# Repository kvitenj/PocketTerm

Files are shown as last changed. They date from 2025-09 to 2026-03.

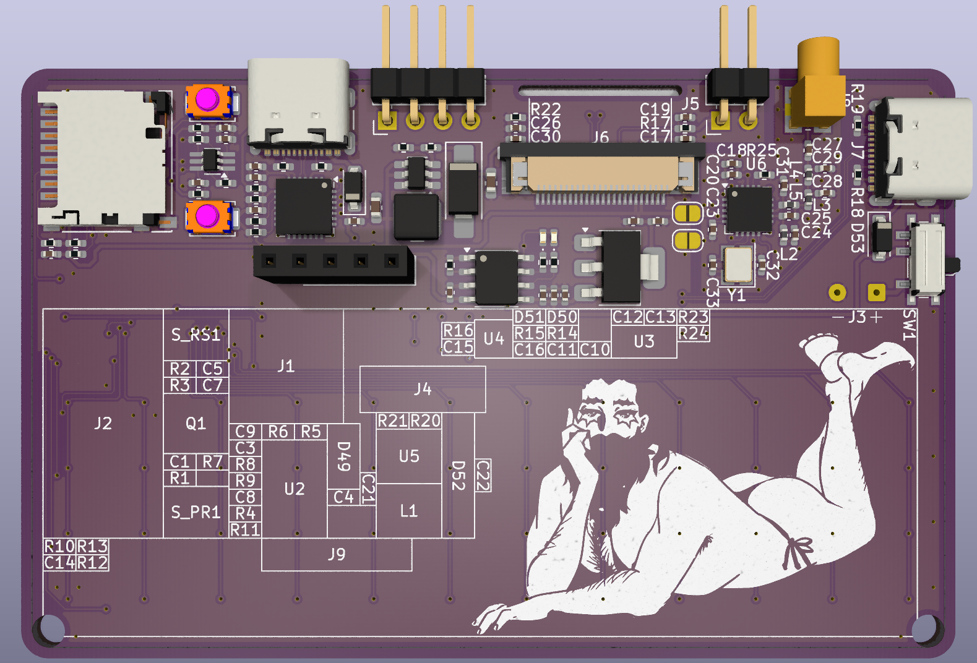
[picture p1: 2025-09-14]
images/board_back.png

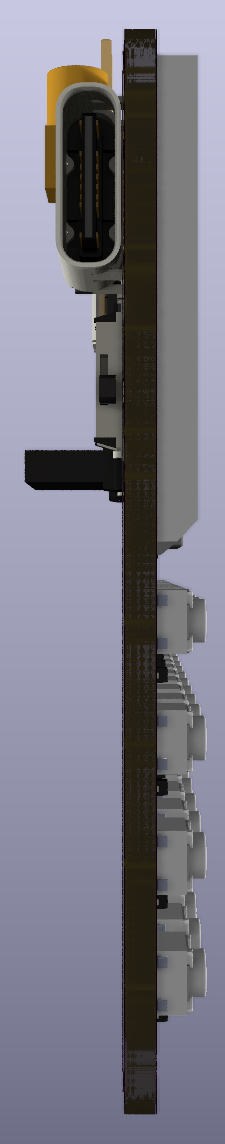
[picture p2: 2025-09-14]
images/board_side.png

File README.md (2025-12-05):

# PocketTerminal

A credit card-sized computer for wireless and wired communication debugging

real_frontreal_backreal_case

---

## 🔖 Overview

The project is inspired by the [M5Stack Cardputer](https://docs.m5stack.com/en/core/Cardputer%20V1.1).

The key features:

- Credit card size to easily fit in any pocket
- QWERTY tactile keyboard for easy and fast command and data input
- "Large" 2.2-inch OLED monochrome LCD with 128x32 resolution. It is monochrome and has less resolution than M5Stack, but it is larger and fits nicely for text terminal data
- ESP32 module as a central processing unit capable of Bluetooth and WiFi communication
- SD card slot for Data storage
- Large and slim battery for long-term operation
- UART, SPI, I2C(TBD) I/O for wired communication debugging
- CC1101 and LoRa(TBD) transceivers for wireless communication debugging

---

## 📁 Repository Contents

| File | Description |
|---|---|
| `PocketTerminalHW` | Folder containing the KiCAD project, PCB and Schematic |
| `images` | Folder containing the concept renders | 
| `LICENSE` | This repository license file |
| `README.md` | This file |

---

## 📬 Contributing

You may submit pull requests or fork the repo. But since it is a hobby project, I may respond with significant delays

---

## 🌸 License

Licensed under the [Flower License](./LICENSE) 🌸

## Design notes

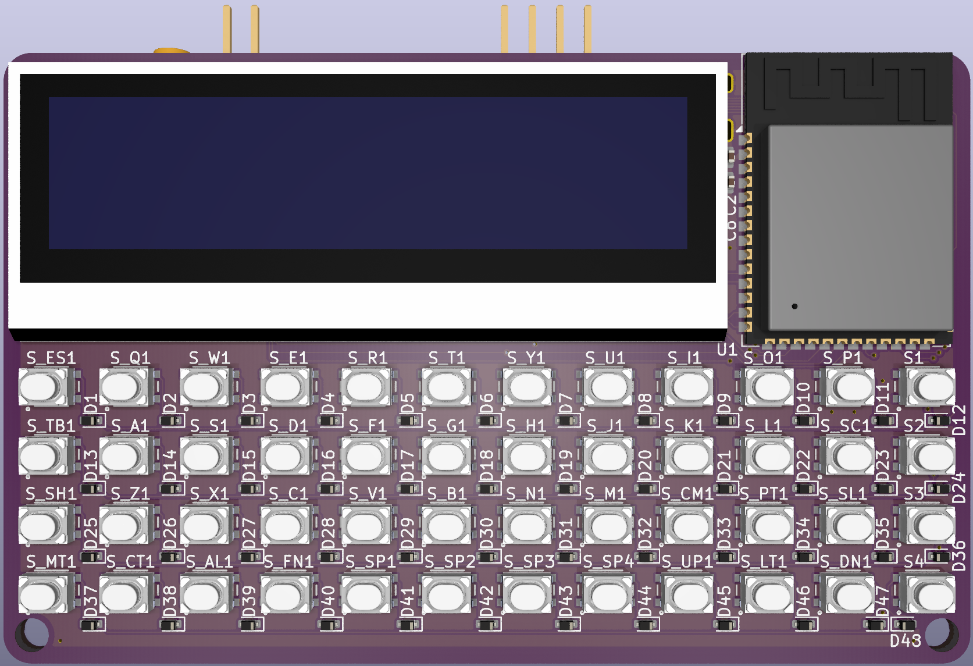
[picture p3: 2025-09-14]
images/board_front.png

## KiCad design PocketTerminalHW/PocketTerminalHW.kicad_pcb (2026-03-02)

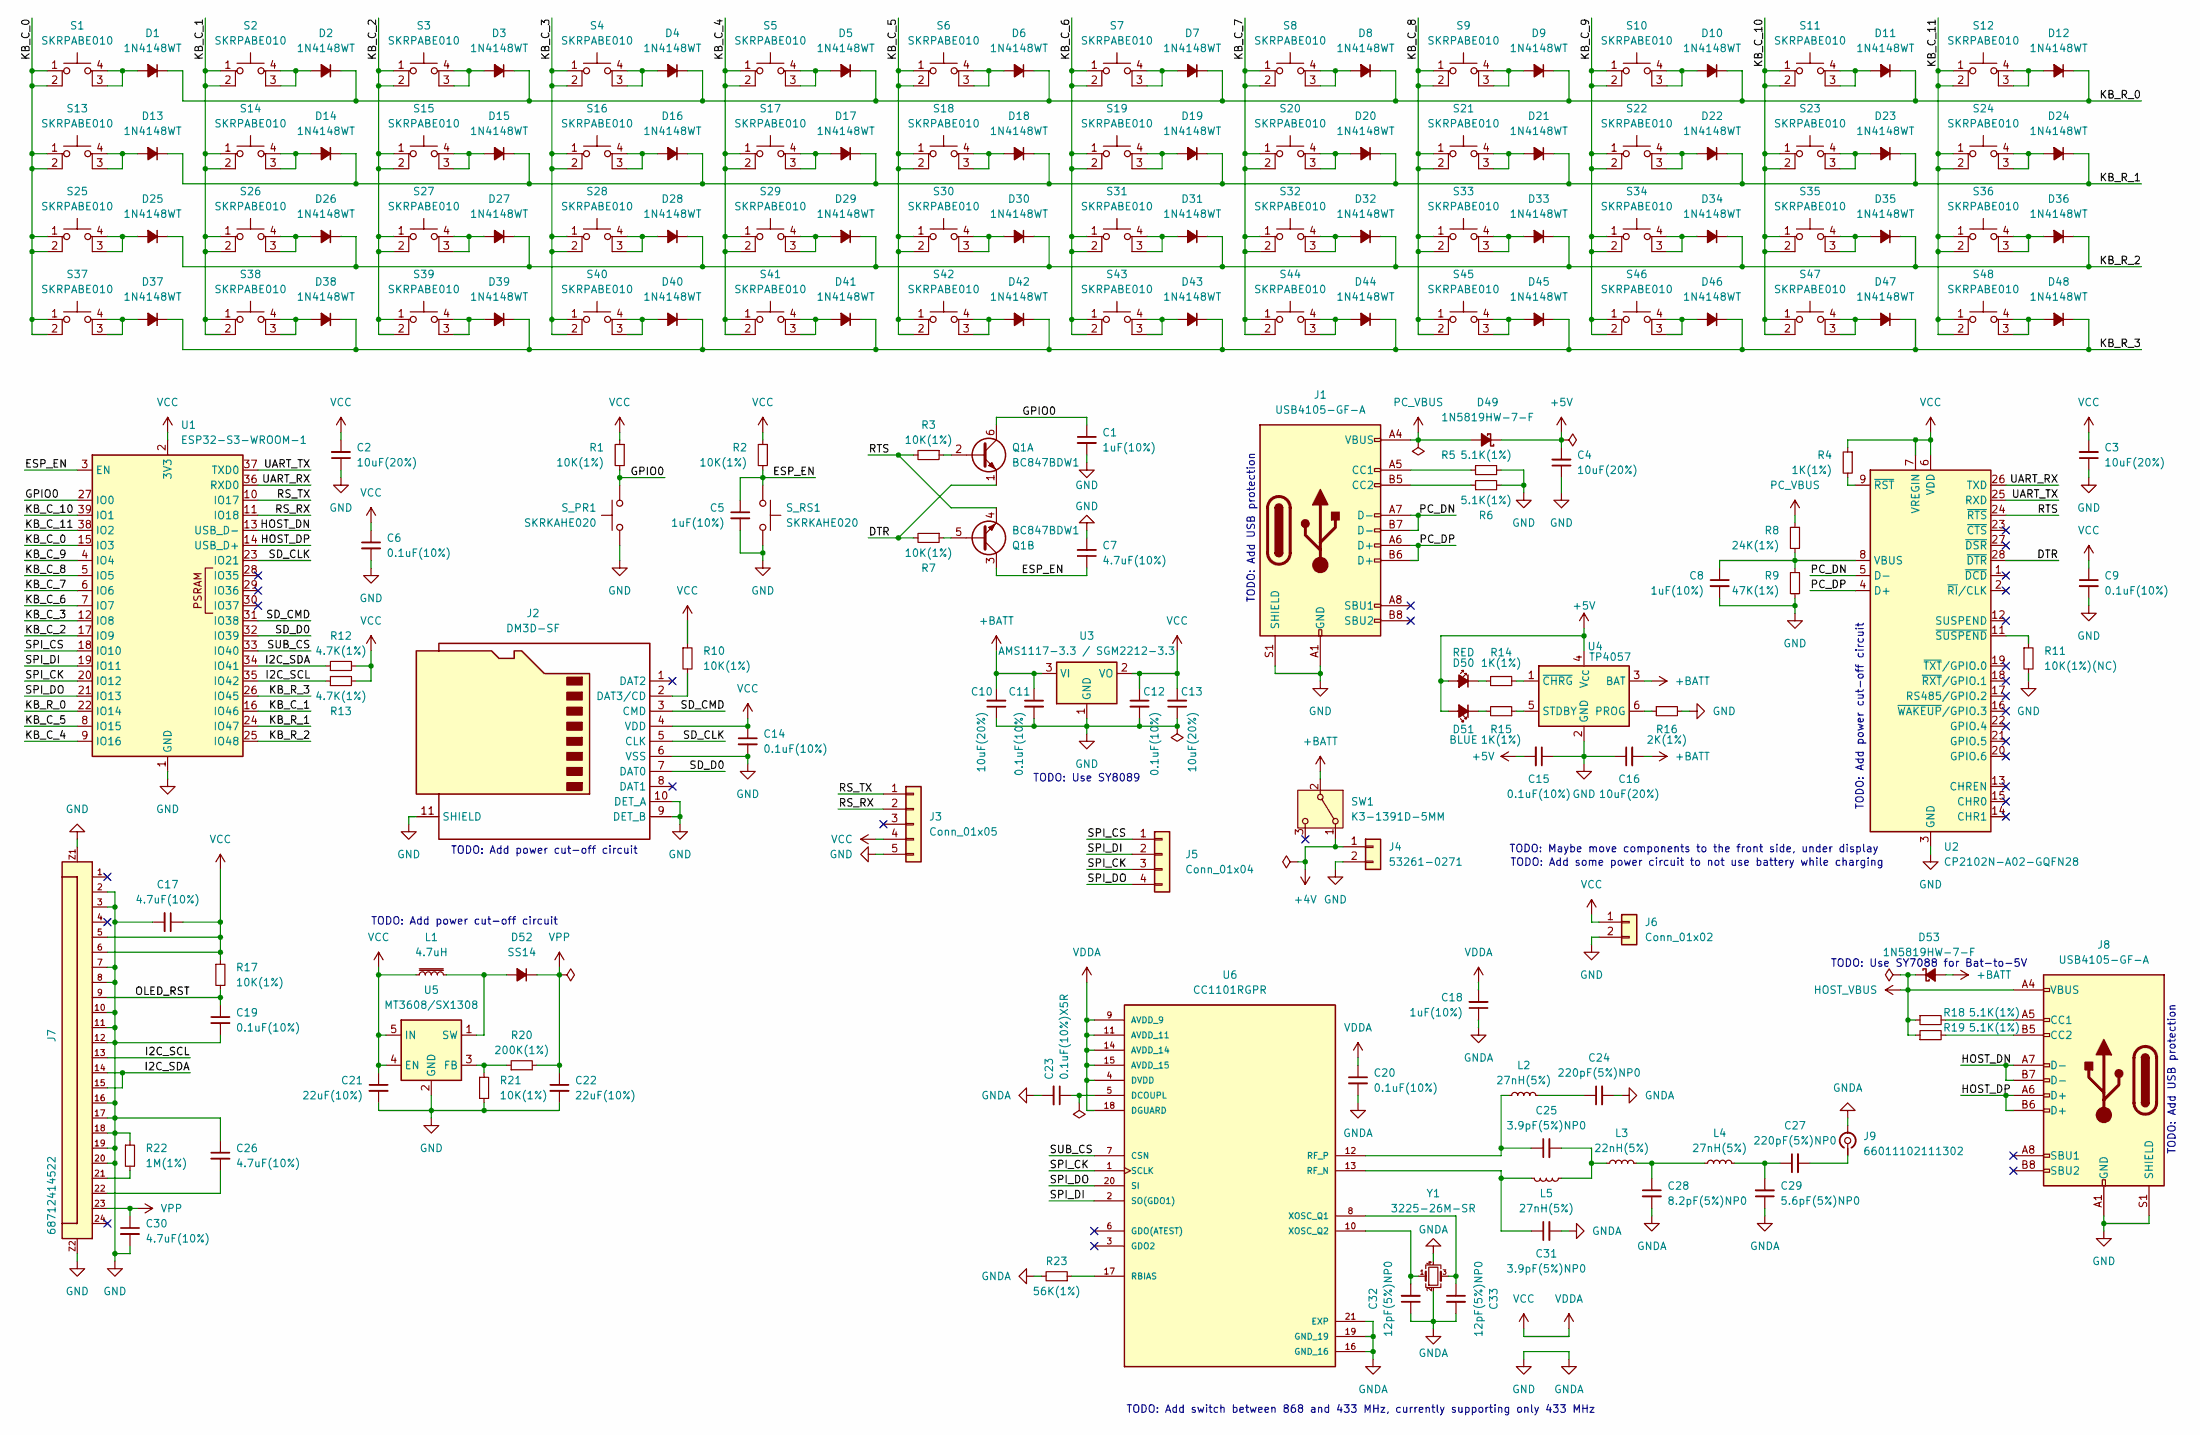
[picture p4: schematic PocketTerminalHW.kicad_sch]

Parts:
C1, C5, C8, C18: 1uF(10%); C_0402_1005Metric_Pad0.74x0.62mm_HandSolder
C2, C3, C4, C10, C13, C16: 10uF(20%); C_0402_1005Metric_Pad0.74x0.62mm_HandSolder
C6, C9, C11, C12, C14, C15, C19, C20: 0.1uF(10%); C_0402_1005Metric_Pad0.74x0.62mm_HandSolder
C7, C17, C26, C30: 4.7uF(10%); C_0402_1005Metric_Pad0.74x0.62mm_HandSolder
C21, C22: 22uF(10%); C_0603_1608Metric_Pad1.08x0.95mm_HandSolder
C23: 0.1uF(10%)X5R; C_0402_1005Metric_Pad0.74x0.62mm_HandSolder
C24, C27: 220pF(5%)NP0; C_0402_1005Metric_Pad0.74x0.62mm_HandSolder
C25, C31: 3.9pF(5%)NP0; C_0402_1005Metric_Pad0.74x0.62mm_HandSolder
C28: 8.2pF(5%)NP0; C_0402_1005Metric_Pad0.74x0.62mm_HandSolder
C29: 5.6pF(5%)NP0; C_0402_1005Metric_Pad0.74x0.62mm_HandSolder
C32, C33: 12pF(5%)NP0; C_0402_1005Metric_Pad0.74x0.62mm_HandSolder
D1, D2, D3, D4, D5, D6, D7, D8, D9, D10, D11, D12, D13, D14, D15, D16, D17, D18, D19, D20, D21, D22, D23, D24, D25, D26, D27, D28, D29, D30, D31, D32, D33, D34, D35, D36, D37, D38, D39, D40, D41, D42, D43, D44, D45, D46, D47, D48: 1N4148WT; D_SOD-523
D49, D53: 1N5819HW-7-F; D_SOD-123
D50: RED; LED_0402_1005Metric
D51: BLUE; LED_0402_1005Metric
D52: SS14; D_SMA
J1, J8: USB4105-GF-A; USB_C_Receptacle_GCT_USB4105-xx-A_16P_TopMnt_Horizontal
J2: DM3D-SF; microSD_HC_Hirose_DM3D-SF
J3: Conn_01x05; PinSocket_1x05_P2.54mm_Vertical
J4: 53261-0271; SolderWire-0.1sqmm_1x02_P3.6mm_D0.4mm_OD1mm
J5: Conn_01x04; PinHeader_1x04_P2.54mm_Horizontal
J6: Conn_01x02; PinHeader_1x02_P2.54mm_Horizontal
J7: 68712414522
J9: 66011102111302; WR-MMCX_Wuerth_66011102111302_Horizontal
L1: 4.7uH; L_Coilcraft_LPS4018
L2, L4, L5: 27nH(5%); L_0402_1005Metric_Pad0.77x0.64mm_HandSolder
L3: 22nH(5%); L_0402_1005Metric_Pad0.77x0.64mm_HandSolder
Q1: BC847BDW1; SOT-363_SC-70-6_Handsoldering
R1, R2, R3, R7, R10, R17, R21: 10K(1%); R_0402_1005Metric_Pad0.72x0.64mm_HandSolder
R4, R14, R15: 1K(1%); R_0402_1005Metric_Pad0.72x0.64mm_HandSolder
R5, R6, R18, R19: 5.1K(1%); R_0402_1005Metric_Pad0.72x0.64mm_HandSolder
R8: 24K(1%); R_0402_1005Metric_Pad0.72x0.64mm_HandSolder
R9: 47K(1%); R_0402_1005Metric_Pad0.72x0.64mm_HandSolder
R11: 10K(1%)(NC); R_0402_1005Metric_Pad0.72x0.64mm_HandSolder
R12, R13: 4.7K(1%); R_0402_1005Metric_Pad0.72x0.64mm_HandSolder
R16: 2K(1%); R_0402_1005Metric_Pad0.72x0.64mm_HandSolder
R20: 200K(1%); R_0402_1005Metric_Pad0.72x0.64mm_HandSolder
R22: 1M(1%); R_0402_1005Metric_Pad0.72x0.64mm_HandSolder
R23: 56K(1%); R_0402_1005Metric_Pad0.72x0.64mm_HandSolder
S1, S2, S3, S4, S5, S6, S7, S8, S9, S10, S11, S12, S13, S14, S15, S16, S17, S18, S19, S20, S21, S22, S23, S24, S25, S26, S27, S28, S29, S30, S31, S32, S33, S34, S35, S36, S37, S38, S39, S40, S41, S42, S43, S44, S45, S46, S47, S48: SKRPABE010; SW4_SKRPABE010_ALPS
SW1: K3-1391D-5MM; SW_SPDT_PCM12
S_PR1: SKRKAHE020; SW_Push_SPST_NO_Alps_SKRK
S_RS1: SKRKAHE020; SW_Push_SPST_NO_Alps_SKRK
U1: ESP32-S3-WROOM-1
U2: CP2102N-A02-GQFN28; QFN-28-1EP_5x5mm_P0.5mm_EP3.35x3.35mm
U3: AMS1117-3.3 / SGM2212-3.3; SOT-223-3_TabPin2
U4: TP4057; TSOT-23-6
U5: MT3608/SX1308; SOT-23-6_Handsoldering
U6: CC1101RGPR; QFN-20-1EP_4x4mm_P0.5mm_EP2.5x2.5mm; PARTREV 6-May-2020
Y1: 3225-26M-SR; Crystal_SMD_3225-4Pin_3.2x2.5mm

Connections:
+4V: J4.1, SW1.1 (A)
+5V: C4.2, C15.2, D49.1 (K), D50.2 (A), D51.2 (A), U4.4 (V_{CC})
+BATT: C10.2, C11.1, C16.2, D53.2 (A), SW1.2 (B), U3.3 (VI), U4.3 (BAT)
/DTR: Q1.1 (E1), R7.2, U2.28 (~DTR)
/ESP_EN: C5.1, C7.1, Q1.3 (C2), R2.2, S_RS1.1, U1.3 (EN)
/GPIO0: C1.1, Q1.6 (C1), R1.2, S_PR1.1, U1.27 (IO0)
/HOST_DN: J8.A7 (D-), J8.B7 (D-), U1.13 (USB_D-)
/HOST_DP: J8.A6 (D+), J8.B6 (D+), U1.14 (USB_D+)
/I2C_SCL: J7.13, R13.1, U1.35 (IO42)
/I2C_SDA: J7.14, J7.15, R12.1, U1.34 (IO41)
/KB_C_0: S1.1, S1.2, S13.1, S13.2, S25.1, S25.2, S37.1, S37.2, U1.15 (IO3)
/KB_C_1: S2.1, S2.2, S14.1, S14.2, S26.1, S26.2, S38.1, S38.2, U1.16 (IO46)
/KB_C_2: S3.1, S3.2, S15.1, S15.2, S27.1, S27.2, S39.1, S39.2, U1.17 (IO9)
/KB_C_3: S4.1, S4.2, S16.1, S16.2, S28.1, S28.2, S40.1, S40.2, U1.12 (IO8)
/KB_C_4: S5.1, S5.2, S17.1, S17.2, S29.1, S29.2, S41.1, S41.2, U1.9 (IO16)
/KB_C_5: S6.1, S6.2, S18.1, S18.2, S30.1, S30.2, S42.1, S42.2, U1.8 (IO15)
/KB_C_6: S7.1, S7.2, S19.1, S19.2, S31.1, S31.2, S43.1, S43.2, U1.7 (IO7)
/KB_C_7: S8.1, S8.2, S20.1, S20.2, S32.1, S32.2, S44.1, S44.2, U1.6 (IO6)
/KB_C_8: S9.1, S9.2, S21.1, S21.2, S33.1, S33.2, S45.1, S45.2, U1.5 (IO5)
/KB_C_9: S10.1, S10.2, S22.1, S22.2, S34.1, S34.2, S46.1, S46.2, U1.4 (IO4)
/KB_C_10: S11.1, S11.2, S23.1, S23.2, S35.1, S35.2, S47.1, S47.2, U1.39 (IO1)
/KB_C_11: S12.1, S12.2, S24.1, S24.2, S36.1, S36.2, S48.1, S48.2, U1.38 (IO2)
/KB_R_0: D1.1 (K), D2.1 (K), D3.1 (K), D4.1 (K), D5.1 (K), D6.1 (K), D7.1 (K), D8.1 (K), D9.1 (K), D10.1 (K), D11.1 (K), D12.1 (K), U1.22 (IO14)
/KB_R_1: D13.1 (K), D14.1 (K), D15.1 (K), D16.1 (K), D17.1 (K), D18.1 (K), D19.1 (K), D20.1 (K), D21.1 (K), D22.1 (K), D23.1 (K), D24.1 (K), U1.24 (IO47)
/KB_R_2: D25.1 (K), D26.1 (K), D27.1 (K), D28.1 (K), D29.1 (K), D30.1 (K), D31.1 (K), D32.1 (K), D33.1 (K), D34.1 (K), D35.1 (K), D36.1 (K), U1.25 (IO48)
/KB_R_3: D37.1 (K), D38.1 (K), D39.1 (K), D40.1 (K), D41.1 (K), D42.1 (K), D43.1 (K), D44.1 (K), D45.1 (K), D46.1 (K), D47.1 (K), D48.1 (K), U1.26 (IO45)
/OLED_RST: C19.1, J7.9, R17.2
/PC_DN: J1.A7 (D-), J1.B7 (D-), U2.5 (D-)
/PC_DP: J1.A6 (D+), J1.B6 (D+), U2.4 (D+)
/RS_RX: J3.2, U1.11 (IO18)
/RS_TX: J3.1, U1.10 (IO17)
/RTS: Q1.4 (E2), R3.2, U2.24 (~RTS)
/SD_CLK: J2.5 (CLK), U1.23 (IO21)
/SD_CMD: J2.3 (CMD), U1.31 (IO38)
/SD_D0: J2.7 (DAT0), U1.32 (IO39)
/SPI_CK: J5.3, U1.20 (IO12), U6.1 (SCLK)
/SPI_CS: J5.1, U1.18 (IO10)
/SPI_DI: J5.2, U1.19 (IO11), U6.2 (SO(GDO1))
/SPI_DO: J5.4, U1.21 (IO13), U6.20 (SI)
/SUB_CS: U1.33 (IO40), U6.7 (CSN)
/UART_RX: U1.36 (RXD0), U2.26 (TXD)
/UART_TX: U1.37 (TXD0), U2.25 (RXD)
GND: C1.2, C2.1, C3.1, C4.1, C5.2, C6.2, C7.2, C8.2, C9.2, C10.1, C11.2, C12.2, C13.1, C14.2, C15.1, C16.1, C17.2, C18.1, C19.2, C20.2, C21.2, C22.2, C23.2, C24.2, C26.1, C28.2, C29.1, C30.2, C31.2, C32.1, C33.2, J1.A1 (GND), J1.A12 (GND), J1.B1 (GND), J1.B12 (GND), J1.S1 (SHIELD), J2.6 (VSS), J2.9 (DET_B), J2.10 (DET_A), J2.11 (SHIELD), J3.5, J4.2, J6.2, J7.2, J7.3, J7.7, J7.8, J7.10, J7.11, J7.12, J7.16, J7.17, J7.18, J7.19, J7.20, J7.Z1, J7.Z2, J8.A1 (GND), J8.A12 (GND), J8.B1 (GND), J8.B12 (GND), J8.S1 (SHIELD), J9.2 (Ext), R5.2, R6.2, R9.2, R11.2, R16.2, R21.2, R22.1, R23.2, S_PR1.2, S_RS1.2, U1.1 (GND), U1.40 (GND), U1.41 (GND), U2.3 (GND), U2.29 (GND), U3.1 (GND), U4.2 (GND), U5.2 (GND), U6.16 (GND_16), U6.19 (GND_19), U6.21 (EXP), Y1.2, Y1.4
HOST_VBUS: D53.1 (K), J8.A4 (VBUS), J8.A9 (VBUS), J8.B4 (VBUS), J8.B9 (VBUS), R18.1, R19.1
unnamed: C24.1, L2.2
unnamed: C25.2, L3.1, L5.1
unnamed: C26.2, J7.22
unnamed: C27.1, C29.2, L4.2
unnamed: C28.1, L3.2, L4.1
unnamed: D1.2 (A), S1.3 (K), S1.4 (A)
unnamed: D2.2 (A), S2.3 (K), S2.4 (A)
unnamed: D3.2 (A), S3.3 (K), S3.4 (A)
unnamed: D4.2 (A), S4.3 (K), S4.4 (A)
unnamed: D5.2 (A), S5.3 (K), S5.4 (A)
unnamed: D6.2 (A), S6.3 (K), S6.4 (A)
unnamed: D7.2 (A), S7.3 (K), S7.4 (A)
unnamed: D8.2 (A), S8.3 (K), S8.4 (A)
unnamed: D9.2 (A), S9.3 (K), S9.4 (A)
unnamed: D10.2 (A), S10.3 (K), S10.4 (A)
unnamed: D11.2 (A), S11.3 (K), S11.4 (A)
unnamed: D12.2 (A), S12.3 (K), S12.4 (A)
unnamed: D13.2 (A), S13.3 (K), S13.4 (A)
unnamed: D14.2 (A), S14.3 (K), S14.4 (A)
unnamed: D15.2 (A), S15.3 (K), S15.4 (A)
unnamed: D16.2 (A), S16.3 (K), S16.4 (A)
unnamed: D17.2 (A), S17.3 (K), S17.4 (A)
unnamed: D18.2 (A), S18.3 (K), S18.4 (A)
unnamed: D19.2 (A), S19.3 (K), S19.4 (A)
unnamed: D20.2 (A), S20.3 (K), S20.4 (A)
unnamed: D21.2 (A), S21.3 (K), S21.4 (A)
unnamed: D22.2 (A), S22.3 (K), S22.4 (A)
unnamed: D23.2 (A), S23.3 (K), S23.4 (A)
unnamed: D24.2 (A), S24.3 (K), S24.4 (A)
unnamed: D25.2 (A), S25.3 (K), S25.4 (A)
unnamed: D26.2 (A), S26.3 (K), S26.4 (A)
unnamed: D27.2 (A), S27.3 (K), S27.4 (A)
unnamed: D28.2 (A), S28.3 (K), S28.4 (A)
unnamed: D29.2 (A), S29.3 (K), S29.4 (A)
unnamed: D30.2 (A), S30.3 (K), S30.4 (A)
unnamed: D31.2 (A), S31.3 (K), S31.4 (A)
unnamed: D32.2 (A), S32.3 (K), S32.4 (A)
unnamed: D33.2 (A), S33.3 (K), S33.4 (A)
unnamed: D34.2 (A), S34.3 (K), S34.4 (A)
unnamed: D35.2 (A), S35.3 (K), S35.4 (A)
unnamed: D36.2 (A), S36.3 (K), S36.4 (A)
unnamed: D37.2 (A), S37.3 (K), S37.4 (A)
unnamed: D38.2 (A), S38.3 (K), S38.4 (A)
unnamed: D39.2 (A), S39.3 (K), S39.4 (A)
unnamed: D40.2 (A), S40.3 (K), S40.4 (A)
unnamed: D41.2 (A), S41.3 (K), S41.4 (A)
unnamed: D42.2 (A), S42.3 (K), S42.4 (A)
unnamed: D43.2 (A), S43.3 (K), S43.4 (A)
unnamed: D44.2 (A), S44.3 (K), S44.4 (A)
unnamed: D45.2 (A), S45.3 (K), S45.4 (A)
unnamed: D46.2 (A), S46.3 (K), S46.4 (A)
unnamed: D47.2 (A), S47.3 (K), S47.4 (A)
unnamed: D48.2 (A), S48.3 (K), S48.4 (A)
unnamed: D50.1 (K), R14.1
unnamed: D51.1 (K), R15.2
unnamed: D52.2 (A), L1.2, U5.1 (SW)
unnamed: J1.A5 (CC1), R5.1
unnamed: J1.B5 (CC2), R6.1
unnamed: J2.2 (DAT3/CD), R10.2
unnamed: J7.21, R22.2
unnamed: J8.A5 (CC1), R18.2
unnamed: J8.B5 (CC2), R19.2
unnamed: C27.2, J9.1 (In)
unnamed: Q1.2 (B1), R3.1
unnamed: Q1.5 (B2), R7.1
unnamed: C8.1, R8.2, R9.1, U2.8 (VBUS)
unnamed: R4.2, U2.9 (~RST)
unnamed: R11.1, U2.11 (~SUSPEND)
unnamed: R16.1, U4.6 (PROG)
unnamed: R15.1, U4.5 (STDBY)
unnamed: R14.2, U4.1 (~CHRG)
unnamed: R20.1, R21.1, U5.3 (FB)
unnamed: C23.1, U6.5 (DCOUPL)
unnamed: R23.1, U6.17 (RBIAS)
unnamed: C31.1, L5.2, U6.13 (RF_N)
unnamed: C25.1, L2.1, U6.12 (RF_P)
unnamed: C33.1, U6.8 (XOSC_Q1), Y1.3
unnamed: C32.2, U6.10 (XOSC_Q2), Y1.1
PC_VBUS: D49.2 (A), J1.A4 (VBUS), J1.A9 (VBUS), J1.B4 (VBUS), J1.B9 (VBUS), R8.1
VCC: C2.2, C3.2, C6.1, C9.1, C12.1, C13.2, C14.1, C17.1, C18.2, C20.1, C21.1, J2.4 (VDD), J3.4, J6.1, J7.5, J7.6, L1.1, R1.1, R2.1, R4.1, R10.1, R12.2, R13.2, R17.1, U1.2 (3V3), U2.6 (VDD), U2.7 (VREGIN), U3.2 (VO), U5.4 (EN), U5.5 (IN), U6.4 (DVDD), U6.9 (AVDD_9), U6.11 (AVDD_11), U6.14 (AVDD_14), U6.15 (AVDD_15), U6.18 (DGUARD)
VPP: C22.1, C30.1, D52.1 (K), J7.23, R20.2

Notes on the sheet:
TODO: Add power cut-off circuit
TODO: Use SY7088 for Bat-to-5V
TODO: Add switch between 868 and 433 MHz, currently supporting only 433 MHz
TODO: Use SY8089
TODO: Maybe move components to the front side, under display
TODO: Add some power circuit to not use battery while charging
TODO: Add USB protection

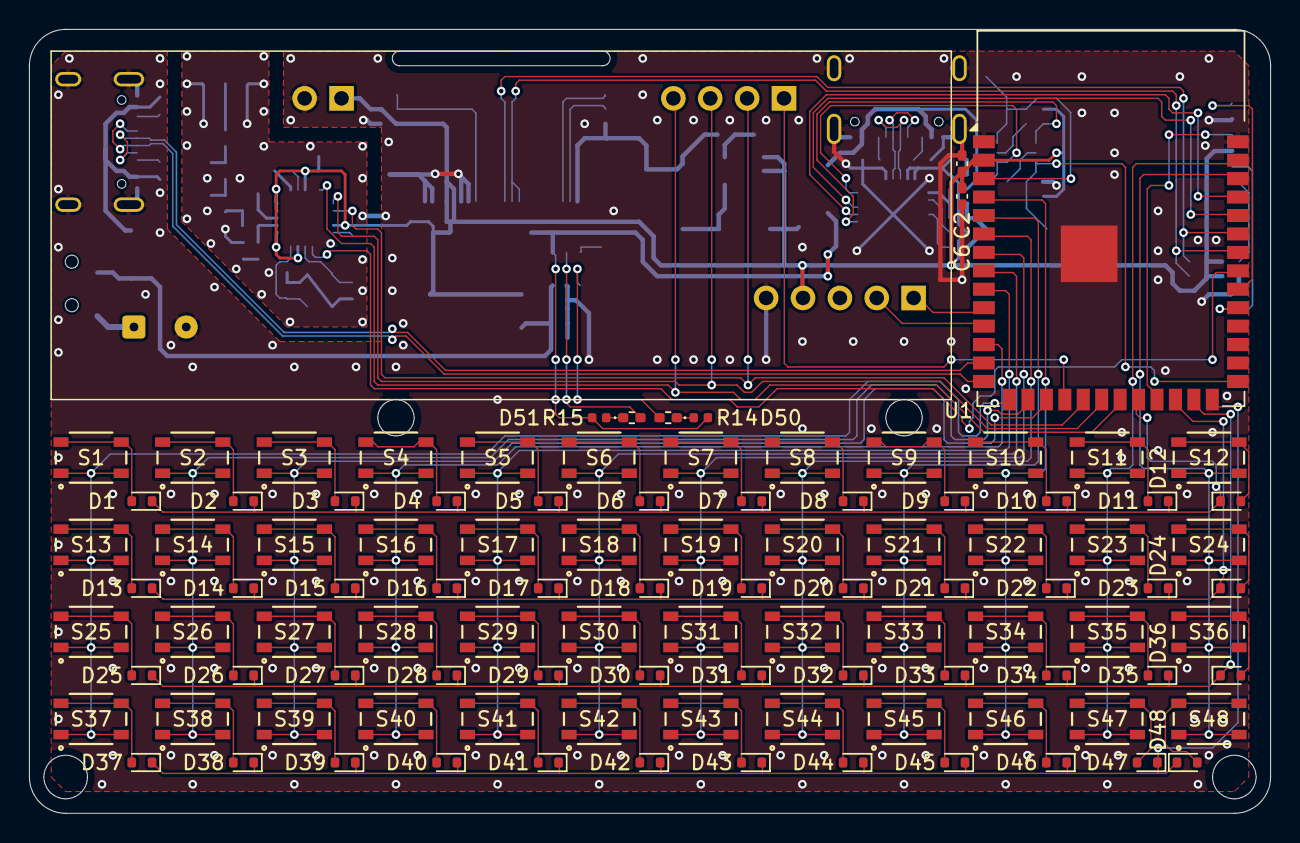
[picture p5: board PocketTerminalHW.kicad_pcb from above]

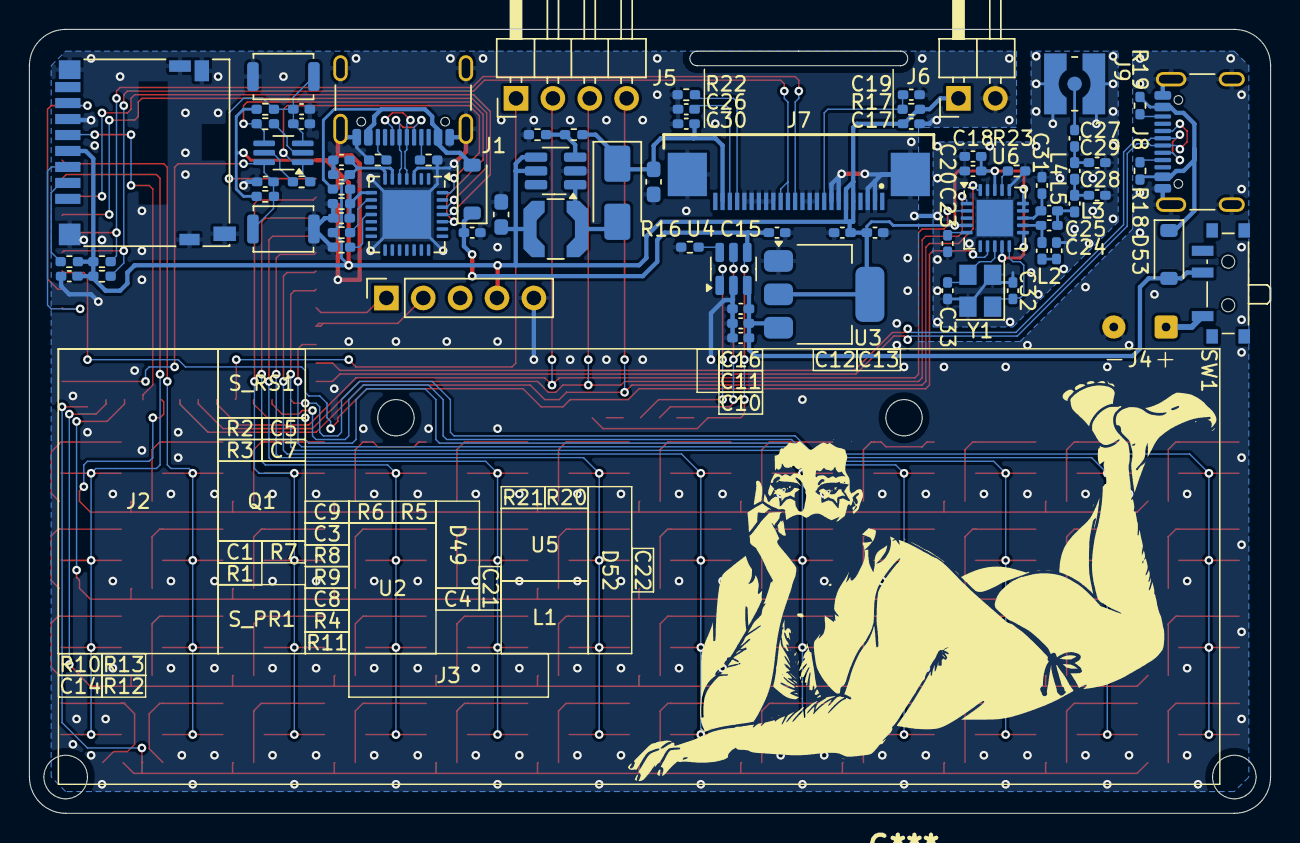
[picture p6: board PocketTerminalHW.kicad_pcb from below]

Board: 2 copper layers, 85.5 x 54.0 mm, 182 parts (79 on the bottom side), 125 nets.

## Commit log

2025-08-27 Schematic and PCB progress Changed ESP module to S3 Added Battery outline Added Program buttons, Auto Program schematic, USB-UART without USB-C socket, SD card socket Finished: ESP, Buttons, Programm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
    [DataSliceHW.kicad_pcb, DataSliceHW.kicad_sch, SKRKAH.STEP]
2025-08-28 Remove componments folder
    [ESP32-C6-WROOM-1_20PCB_20Footprint.dxf, SKRKAH.STEP, SKRPAB.stp]
2025-08-28 Pin adjustments for SD Add display ribbon cable hole
    [DataSliceHW.kicad_pcb, DataSliceHW.kicad_sch]
2025-08-28 Added OLED schematic
    [DataSliceHW.kicad_pcb, DataSliceHW.kicad_sch]
2025-09-03 Schematic and board progress
    Updated gitignore and removed some ignored files
    Added power schematic with battery chagrer
    Some adjustments to components
    [DataSliceHW.kicad_pcb, DataSliceHW.kicad_sch]
2025-09-05 Board adjustments and some renders
    [DataSliceHW.kicad_pcb, DataSliceHW.kicad_sch]
2025-09-09 CC1101 progress
    [DataSliceHW.kicad_pcb, DataSliceHW.kicad_sch]
2025-09-09 Added USB host and finished CC1110 schematic
    [DataSliceHW.kicad_sch]
2025-09-09 ERC correction
    [DataSliceHW.kicad_sch]
2025-09-11 Minor schematic changes and some PCB tracing progress
    [DataSliceHW.kicad_pcb, DataSliceHW.kicad_sch]
2025-09-12 PCB progress
    [DataSliceHW.kicad_pcb]
2025-09-14 Finalized firt prototype Completed PCB design Finalized schematic
    [DataSliceHW.kicad_pcb, DataSliceHW.kicad_sch]
2025-09-14 Minor silkscreen update
    [DataSliceHW.kicad_pcb]
2025-09-18 Minor PCB changes
    [DataSliceHW.kicad_pcb, DataSliceHW.kicad_sch]
2025-09-18 Project rename and minor PCB changes
    [PocketTerminalHW.kicad_pcb, PocketTerminalHW.kicad_sch]
2025-09-19 Switch images to PCB renders
2025-09-20 Minor PCB adjustments, change charger to TP4057
    [PocketTerminalHW.kicad_pcb, PocketTerminalHW.kicad_sch]
2025-09-20 Moved mounting holes
    [PocketTerminalHW.kicad_pcb, PocketTerminalHW.kicad_sch]
2025-09-22 Minor cnages to cap values
    [PocketTerminalHW.kicad_sch]
2025-12-05 Added photos of prototype
2026-03-02 Second proto WIP
    [PocketTerminalHW.kicad_pcb, PocketTerminalHW.kicad_sch]
2026-03-02 Corrected file attributes
    [PocketTerminalHW.kicad_pcb, PocketTerminalHW.kicad_sch]
